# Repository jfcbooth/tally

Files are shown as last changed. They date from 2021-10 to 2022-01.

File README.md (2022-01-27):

# Tally
 
A battery-powered seven-segment display counter using a custom PCB. A counter like this can have many unique purposes and can be quickly modified to serve new purpose.
<p align="center">
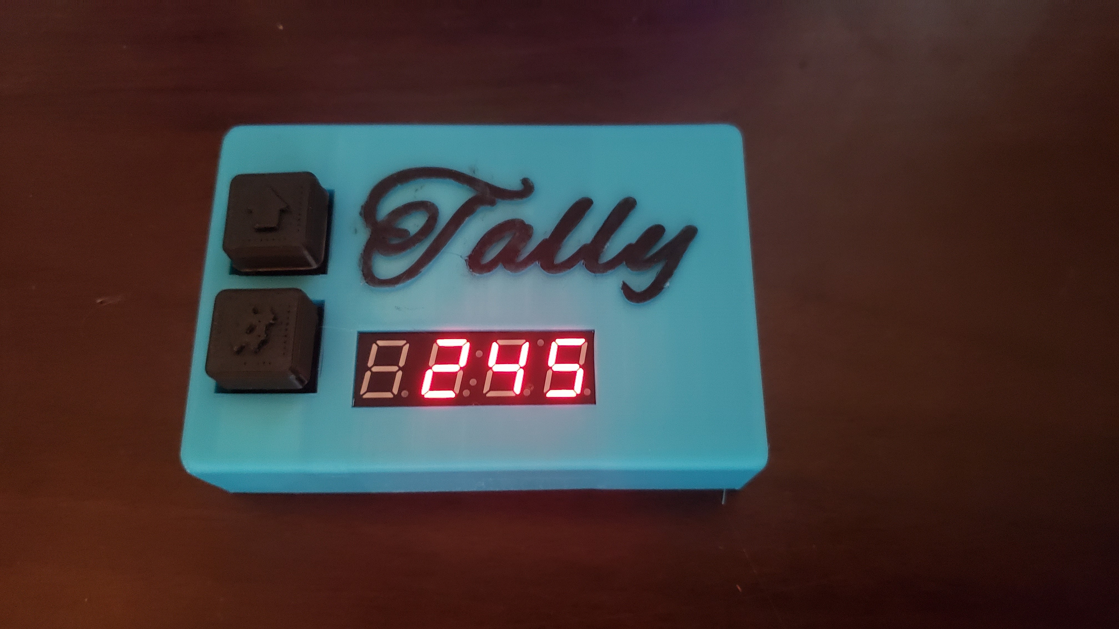
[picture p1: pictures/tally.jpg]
TT

</p>

## Resetting the tally
To reset the counter to 0, press either button to wake the device from sleep, then press the small yellow button on the back of the PCB (labelled BTN).

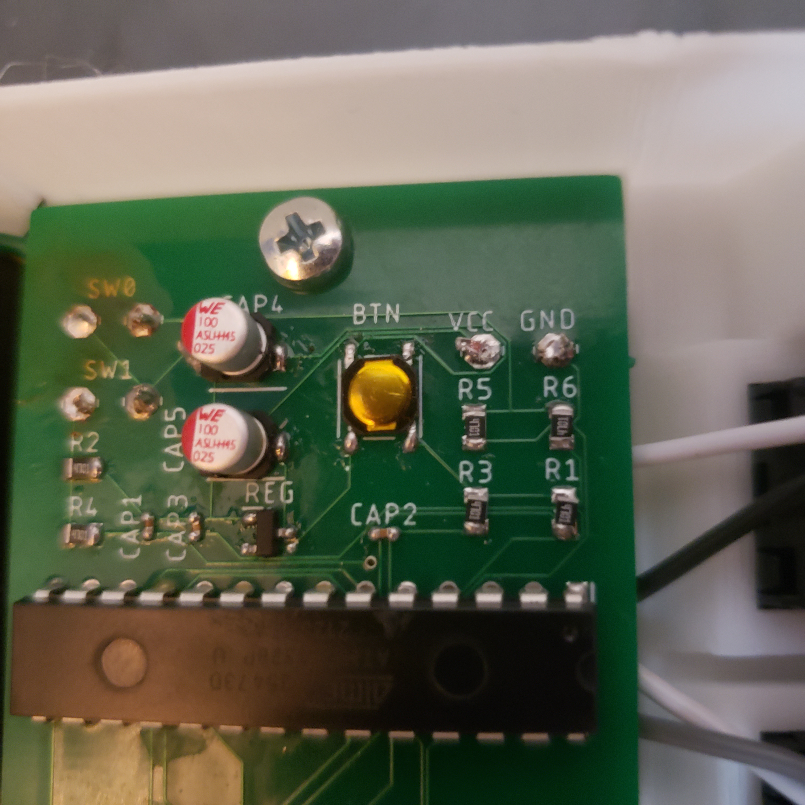
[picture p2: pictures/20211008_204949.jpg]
BTN


All files necessary to build one for yourself are included in this repository.

<!-- START doctoc generated TOC please keep comment here to allow auto update -->
<!-- DON'T EDIT THIS SECTION, INSTEAD RE-RUN doctoc TO UPDATE -->

- [ATMEGA328 Software](#atmega328-software)
- [PCB](#pcb)
- [Case](#case)

<!-- END doctoc generated TOC please keep comment here to allow auto update -->

## ATMEGA328 Software
1.) Burn Fuses
 - Open arduino software and add the MiniCore library to your board manager:  
 Preferences->Additional Board Manager URLS->paste https://mcudude.github.io/MiniCore/package_MCUdude_MiniCore_index.json  
 - Tools->Board Manager->Search "minicore"->Install  
 - Upload asrduinoISP sketch from arduino software to an arduino uno.  
 - Connect to ATMEGA as shown here:  

| Configured with internal clock | Configured with external clock |
| --- | --- |
| To flash ATMEGA | 16Mhz clock flash |

Arduino Flash Options:  
Board->Minicore->ATMEGA328P  
Clock->Internal 1Mhz  
BOD->1.8V  
EEPROM->EEPROM retained  
Compiler LTO->LTO disabled  
Variant->328P/328A  
Bootloader->No bootloader  
PORT-> select your COM port  
Programmer->Arduino as ISP  
Burn bootloader  

Trying configuring the ATMEGA328 with the internal clock first, but if the code doesn't upload, it was probably configured to use an external 16Mhz clock from the factory. You will need a 16Mhz clock which can be de-soldered from an old/dead arduino and 2 22nF capacitors. After burning the bootloader (which sets the fuses), you can remove the crystal and won't need it when uploading sketches from now on. If the code still doesn't upload, make sure all grounds are connected and the supplied voltage is >3V.

2.) Upload Sketch  
 - Open arduino sketch in src  
 - Upload as programmer  (shift click on upload button)

3.) Install ATMEGA328P into PCB  (Note the orientation)

## PCB
| Hardware | Quantity | Purchase location |
| ---  | ---  | ---  |
| ATMEGA328P-PU | 1 | [mouser](https://www.mouser.com/ProductDetail/556-ATMEGA328P-PU) |
| TDCR1050M | 1 | [mouser](https://www.mouser.com/ProductDetail/78-TDCR1050M) |
| C0402C103K5RAC7411 | 4 | [mouser](https://www.mouser.com/ProductDetail/80-C0402C103K5R7411) |
| TPS7A0520PDBZR | 1 | [mouser](https://www.mouser.com/ProductDetail/595-TPS7A0520PDBZR) |
| CRCW08054K70FKEAC | 6 | [mouser](https://www.mouser.com/ProductDetail/71-CRCW08054K70FKEAC) |
| 865080440002 | 2 | [mouser](https://www.mouser.com/ProductDetail/710-865080440002) |
| PTS526 SK08 SMTR2 LFS | 1 | [mouser](https://www.mouser.com/ProductDetail/611-PTS526SK08SMTR2L) |
| 2468 | 1 | [mouser](https://www.mouser.com/ProductDetail/534-2468) |
| Cherry MX Switch Blue | 2 | [amazon](https://www.amazon.com/Cherry-switches-MX1AG1NN-Mechanical-Keyboard/dp/B07RQTNS58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) |

I ordered my PCB's through JLCPCB.  
If ordering through them, you can just upload the tally_cam_data.zip zip file in the schematics folder to their website.  
I was supposed to be able to make this design at my university, but none of my professors know how to use the lab eqipment, so I had to order them through a 3rd party. Go Raiders!  

1.) Solder components to PCB (except cherry mx switches)  
2.) Install battery box first by sliding it into place  
3.) Screw PCB into place  
4.) Install Cherry MX switches and solder them to the board  

## Case
For the case, orient it standing tall with the cherry mx switches toward the top.  
It needs printed with a .2mm nozzle for the front lettering to print properly.  
The case is 3d printed, for the back plate, print it laying flat.

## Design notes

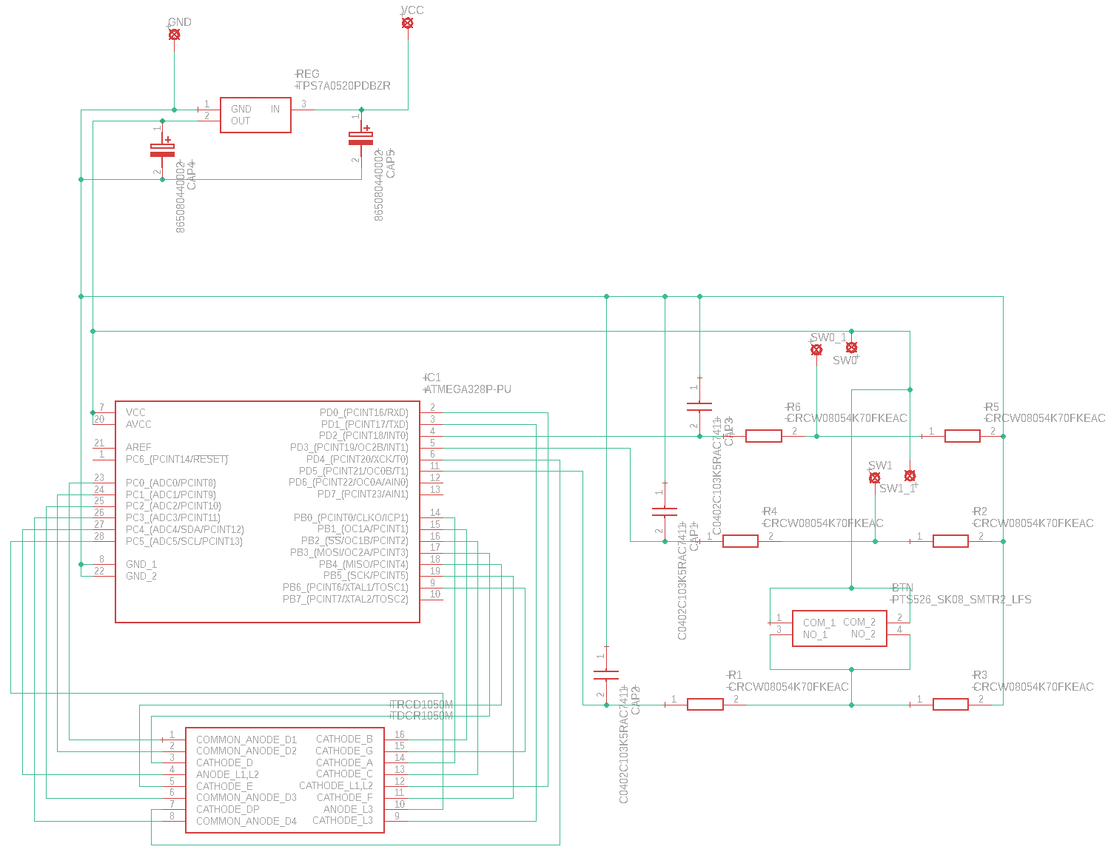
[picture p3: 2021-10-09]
pictures/tally_schematic.png

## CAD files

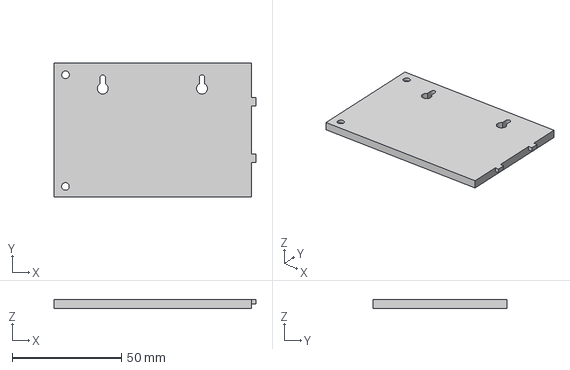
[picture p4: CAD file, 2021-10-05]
case_design/back_cover.3mf
92.6 x 61.4 x 4.00 mm

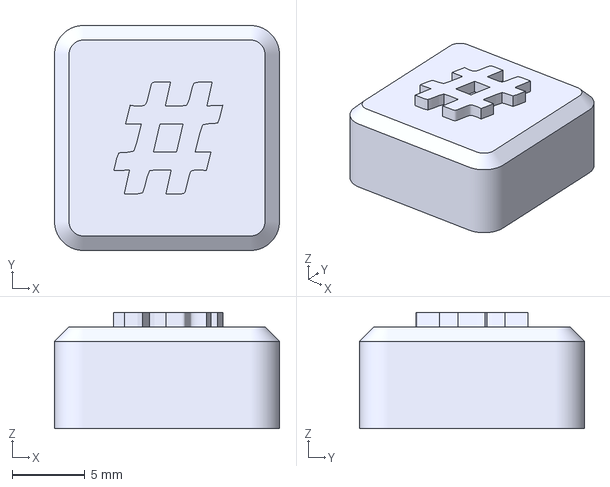
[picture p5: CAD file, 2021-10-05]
case_design/number_keycap.3mf
15.5 x 15.5 x 8.00 mm

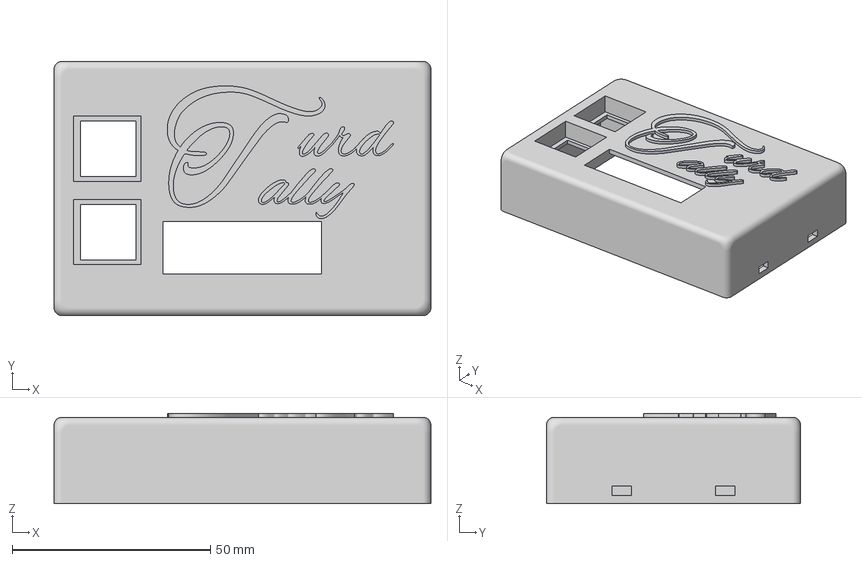
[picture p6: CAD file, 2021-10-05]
case_design/case.3mf
95.2 x 64.2 x 22.8 mm

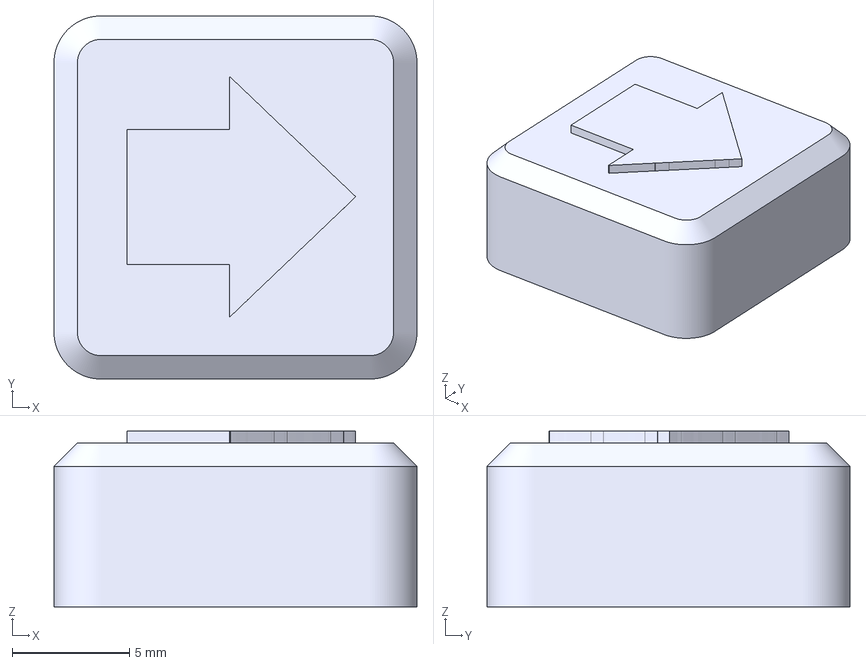
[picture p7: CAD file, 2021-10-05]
case_design/arrow_keycap.3mf
15.5 x 15.5 x 7.50 mm

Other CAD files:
case_design/up_keycap.3mf

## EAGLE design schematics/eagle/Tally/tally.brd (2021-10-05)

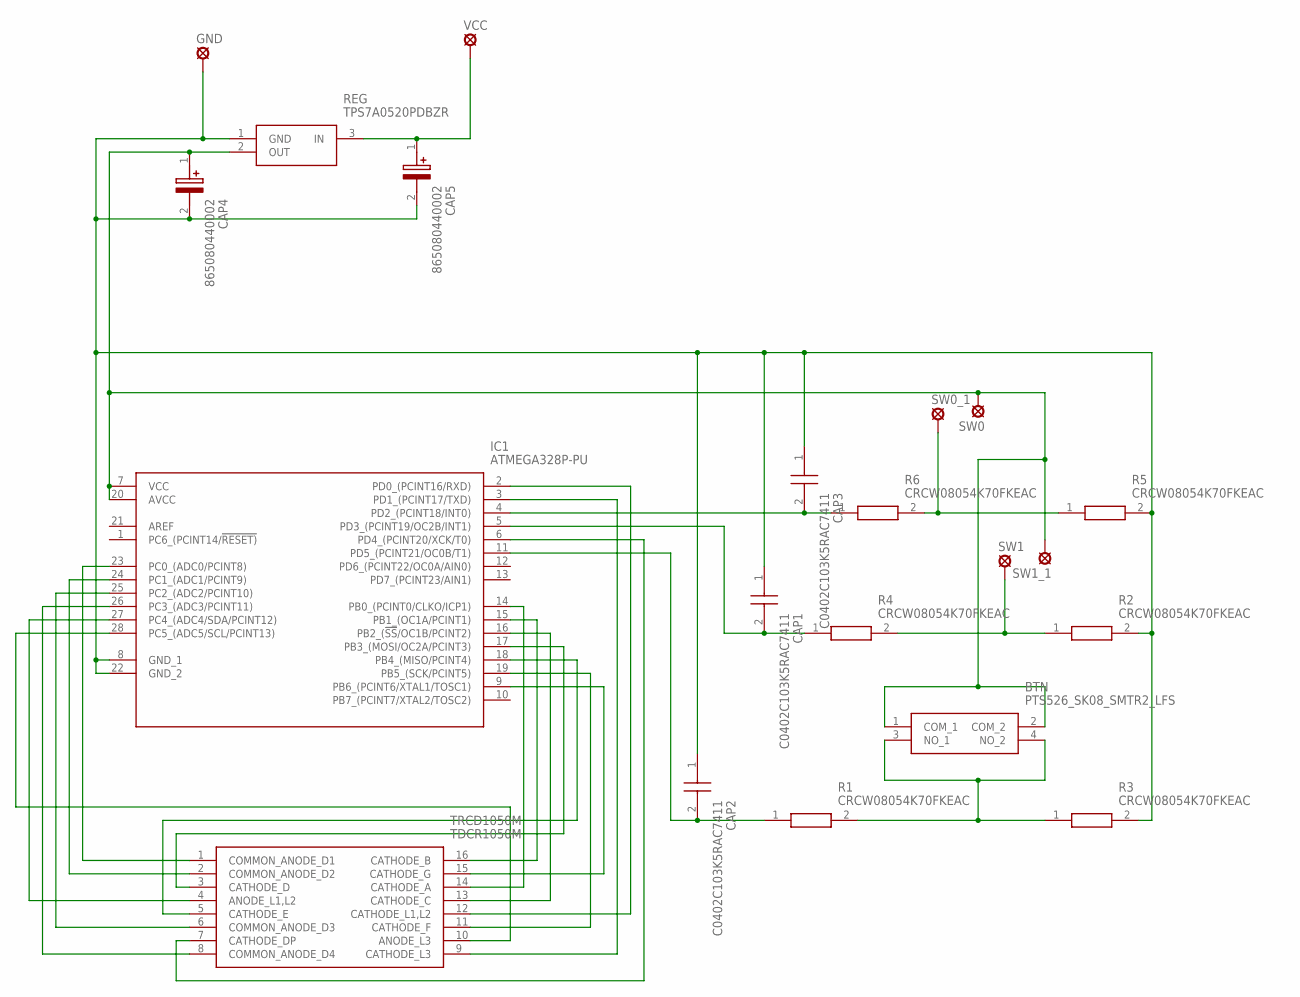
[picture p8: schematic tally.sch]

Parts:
BTN: PTS526_SK08_SMTR2_LFS; PTS526SKG15SMTR2LFS
CAP1, CAP2, CAP3: C0402C103K5RAC7411; CAPC1005X55N
CAP4, CAP5: 865080440002; CAPAE400X550N
GND: LSP11
IC1: ATMEGA328P-PU; DIP794W53P254L3467H457Q28N
R1, R2, R3, R4, R5, R6: CRCW08054K70FKEAC; RESC2012X60N
REG: TPS7A0520PDBZR; SOT95P237X112-3N
SW0, SW0_1, SW1, SW1_1: LSP11
TRCD1050M: TDCR1050M; DIPS1016W50P254L4020H725Q16N
VCC: LSP11

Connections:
unnamed: CAP1.1, CAP2.1, CAP3.1, CAP4.2 (-), CAP5.2 (-), GND.MP, IC1.8 (GND_1), IC1.22 (GND_2), R2.2, R3.2, R5.2, REG.1 (GND)
unnamed: CAP5.1 (+), REG.3 (IN), VCC.MP
unnamed: IC1.14 (PB0_(PCINT0/CLKO/ICP1)), TRCD1050M.14 (CATHODE_A)
unnamed: IC1.15 (PB1_(OC1A/PCINT1)), TRCD1050M.16 (CATHODE_B)
unnamed: IC1.16 (PB2_(!SS!/OC1B/PCINT2)), TRCD1050M.13 (CATHODE_C)
unnamed: IC1.17 (PB3_(MOSI/OC2A/PCINT3)), TRCD1050M.3 (CATHODE_D)
unnamed: IC1.18 (PB4_(MISO/PCINT4)), TRCD1050M.5 (CATHODE_E)
unnamed: IC1.19 (PB5_(SCK/PCINT5)), TRCD1050M.11 (CATHODE_F)
unnamed: IC1.9 (PB6_(PCINT6/XTAL1/TOSC1)), TRCD1050M.15 (CATHODE_G)
unnamed: IC1.23 (PC0_(ADC0/PCINT8)), TRCD1050M.1 (COMMON_ANODE_D1)
unnamed: IC1.24 (PC1_(ADC1/PCINT9)), TRCD1050M.2 (COMMON_ANODE_D2)
unnamed: IC1.25 (PC2_(ADC2/PCINT10)), TRCD1050M.6 (COMMON_ANODE_D3)
unnamed: IC1.26 (PC3_(ADC3/PCINT11)), TRCD1050M.8 (COMMON_ANODE_D4)
unnamed: IC1.27 (PC4_(ADC4/SDA/PCINT12)), TRCD1050M.4 (ANODE_L1,L2)
unnamed: IC1.28 (PC5_(ADC5/SCL/PCINT13)), TRCD1050M.10 (ANODE_L3)
unnamed: IC1.2 (PD0_(PCINT16/RXD)), TRCD1050M.12 (CATHODE_L1,L2)
unnamed: IC1.3 (PD1_(PCINT17/TXD)), TRCD1050M.9 (CATHODE_L3)
unnamed: IC1.6 (PD4_(PCINT20/XCK/T0)), TRCD1050M.7 (CATHODE_DP)
unnamed: R5.1, R6.2, SW0_1.MP
unnamed: CAP3.2, IC1.4 (PD2_(PCINT18/INT0)), R6.1
unnamed: CAP1.2, IC1.5 (PD3_(PCINT19/OC2B/INT1)), R4.1
unnamed: R2.1, R4.2, SW1.MP
unnamed: CAP2.2, IC1.11 (PD5_(PCINT21/OC0B/T1)), R1.1
unnamed: BTN.1 (COM_1), BTN.2 (COM_2), CAP4.1 (+), IC1.7 (VCC), IC1.20 (AVCC), REG.2 (OUT), SW0.MP, SW1_1.MP
unnamed: BTN.3 (NO_1), BTN.4 (NO_2), R1.2, R3.1

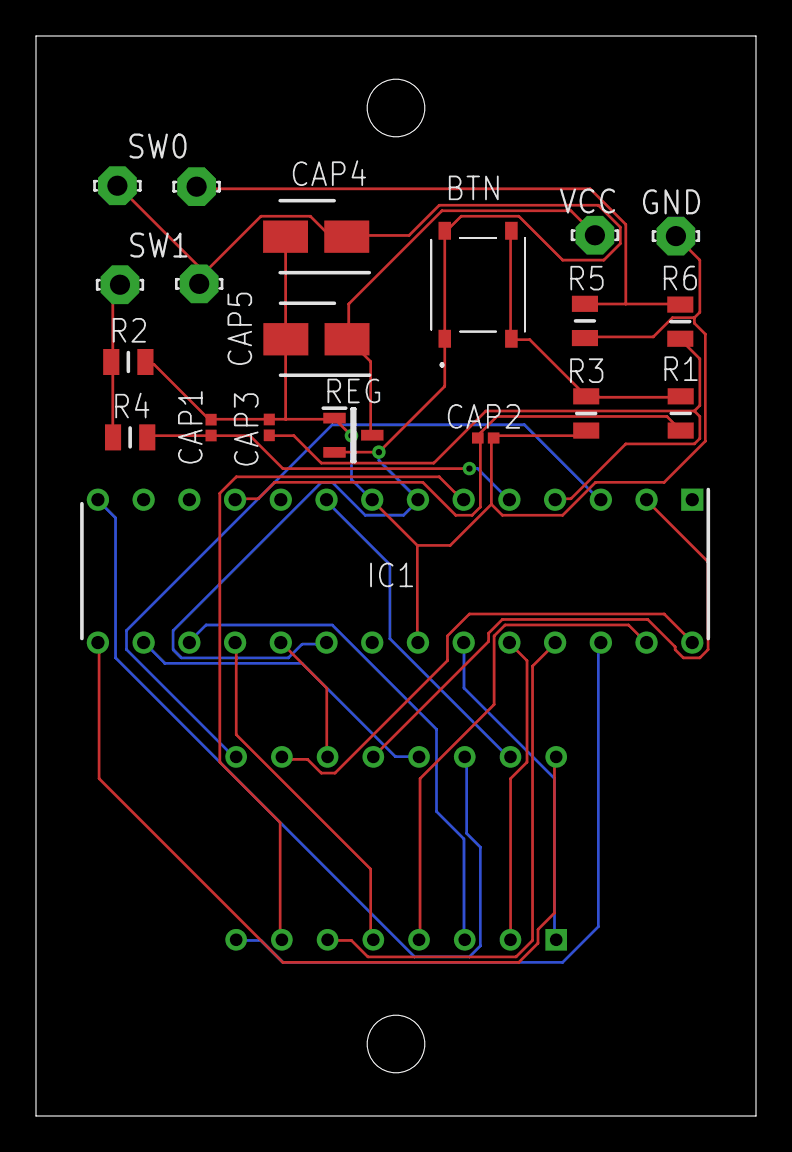
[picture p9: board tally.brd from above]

Board: 2 copper layers, 40.0 x 60.0 mm, 21 parts (1 on the bottom side), 25 nets.

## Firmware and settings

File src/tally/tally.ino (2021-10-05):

/*
 * AVR_GPIO.c
 *
 * Created: 7/27/2021 7:10:25 PM
 * Author : Josh Booth
 */ 

#undef F_CPU
#define F_CPU 1000000UL
#define DISP_ON_TIME 5
#define DIGIT_DELAY 25
#define NUM_OF_OVERFLOWS 100 // try 125 next
#define HZ_PER_1SEC 977

#include <avr/io.h>
#include <util/delay.h>
#include <EEPROM.h>
#include <avr/interrupt.h> // header to enable interrupt
#include <avr/sleep.h>

void zero(void);
void one(void);
void two(void);
void three(void);
void four(void);
void five(void);
void six(void);
void seven(void);
void eight(void);
void nine(void);
void digit_off(void);
void all_off(void);
void set_digit(int digit, int number);
void setup(void);
void display_int(int num);
void delay_1_sec(void);
void update_digits_array(int tally, int set_zero);
int read_tally(void);
void write_tally(int tally);

int turd_tally = 0; // actual tally
int disp_on_time = 0; // seconds left to keep display on for
int digits[4]; // digits to display on timer

// display current tally interrupt
ISR(INT0_vect){
  SMCR &= ~(0<<SE); // sleep_disable();
  update_digits_array(turd_tally, 0);
  disp_on_time = DISP_ON_TIME; // set number of seconds to keep display on for
  TCNT1 = 0; // reset DISP_ON_TIME timer
}

// increment interrupt
ISR(INT1_vect){
  SMCR &= ~(1<<SE); // sleep_disable();
  turd_tally = (turd_tally >= 9999) ? 1 : turd_tally+1; // make sure timer can't go above 9999
  write_tally(turd_tally); // reflect increment in EEPROM
  update_digits_array(turd_tally, 0); // change digits array so it shows on the display
  disp_on_time = DISP_ON_TIME;
  TCNT1 = 0; // reset DISP_ON_TIME timer
}

 
int main(void)
{
  setup();
  turd_tally = read_tally(); // restore value on boot
  
  all_off(); // make sure all LEDs start as off
  int digit_to_display = 0;
  int overflows = 0;
    while (true) 
    {
      
      if(TCNT1 >= HZ_PER_1SEC){ // every second decrement the number of seconds to keep the display on
        disp_on_time = (disp_on_time > 0) ? disp_on_time-1 : 0;
        TCNT1 = 0; // reset timer
      }
      // reset if reset button is pressed
      if((PIND & 0x20)){
        write_tally(0);
        turd_tally = 0;
        update_digits_array(turd_tally, 1);
      }
      // turn on display
      if(disp_on_time > 0){
        // next 2 if statments control how long each digit is displayed between the 4 digits
        if((TIFR0 & (1<<TOV1))==1){ // digit flicker timer
          overflows++;
          TCNT0 = 0; // reset timer
          TIFR0 &= 0b0;
        }
        if(overflows >= NUM_OF_OVERFLOWS){ // if enough overflows have passed, move to the next digit
          set_digit(digit_to_display+1,digits[digit_to_display]);
          digit_to_display = (digit_to_display >= 3) ? 0 : digit_to_display+1;
          overflows=0;
        }
      } else {
        PORTC = 0b00000000; // turn off the display
        SMCR |= 0b1; // enable sleep bit
        MCUCR |= (0b11<<6); // turn off brown out detection
        MCUCR |= (0b10<<6);
        asm("SLEEP"); // sleep instruction
      }
    }
                      
}

void update_digits_array(int tally, int set_zero){
  if(set_zero == 1){
    digits[3] = -1;
    digits[2] = -1;
    digits[1] = -1;
    digits[0] = 0;
    return;
  }
  static int temp_tally = -1;
  if(temp_tally != tally){ // if tally changed, recalculate digits;
    temp_tally = tally;
    for(int i = 0; i < 4; i++){
      digits[i] = (temp_tally - ((temp_tally / 10)*10));
      temp_tally /= 10;
    }
    int i = 3; // replace leading 0's with -1
    while(digits[i] == 0 && i > 0){
      digits[i] = -1;
      i--;
    }
  }  
}

// set proper bits to output
void setup(void){
    MCUCR &= (0 << PUD); // set internal pull-up resistor
    EICRA = 0b1010; // set external interrupts to occur on falling edge (button release)
    EIMSK = 0b11; // enable external interrupts 0 and 1
    sei(); // enable global interrupts
    // I/O inputs and outputs (1 == output, 0 == input)
    DDRB = 0b01111111;
    DDRC = 0b00111111;
    DDRD = 0b00010011;
    TCCR0B |= ((1 << CS12) | (1 << CS10)); // 8-bit timer, 1024 prescalar
    TCCR1B |= ((1 << CS12) | (1 << CS10)); // 16-bit timer, 1024 prescalar, 1 second passes at tick 15625
    PRR = 0b11000111;
    SMCR |= (0b010 << 1);
}

int read_tally(void){
  return ((EEPROM.read(1) << 8) |  
  
  (EEPROM.read(0) & 0b11111111));
  //return EEPROM.read(0);
}

void write_tally(int tally){
  EEPROM.write(0, (tally & 0b11111111));
  EEPROM.write(1, ((tally>>8) & 0b11111111));
}

void set_digit(int digit, int number){
  PORTC = 0b00000000; // to avoid ghosting due to the slow clock signal, turn off the digits, set the proper number bits, then turn the digit on
  switch(number){
    case 0:
      zero();
      break;
    case 1:
      one();
      break;
    case 2:
      two();
      break;
    case 3:
      three();
      break;
    case 4:
      four();
      break;
    case 5:
      five();
      break;
    case 6:
      six();
      break;
    case 7:
      seven();
      break;
    case 8:
      eight();
      break;
    case 9:
      nine();
      break;
    default:
      digit_off();
      break;
  }
  
  switch(digit){
    case 1:
      PORTC = 0b00001000;
      break;
    case 2:
      PORTC = 0b00000100;
      break;
    case 3:
      PORTC = 0b00000010;
      break;
    case 4:
      PORTC = 0b00000001;
      break;
    case 5: // colon
      PORTC = 0b00010000;
      break;
    case 6: // degree symbol
      PORTC = 0b00010000;
      break;
    default:
      PORTC = 0b00000000;
      break;
  }
}


void zero(void){
  PORTB = 0b01000000;
  PORTD |= (1<<4) | (1<<1) | (1<<2);
}

void one(void){
  PORTB = 0b01111001;
  PORTD |= (1<<4) | (1<<1) | (1<<2);

}

void two(void){
  PORTB = 0b00100100;
  PORTD |= (1<<4) | (1<<1) | (1<<2);

}


void three(void){
  PORTB = 0b00110000;
  PORTD |= (1<<4) | (1<<1) | (1<<2);

}

void four(void){
  PORTB = 0b00011001;
  PORTD |= (1<<4) | (1<<1) | (1<<2);

}

void five(void){

  PORTB = 0b00010010;
  PORTD |= (1<<4) | (1<<1) | (1<<2);

}

void six(void){
  PORTB = 0b00000010;
  PORTD |= (1<<4) | (1<<1) | (1<<2);

}

void seven(void){
  PORTB = 0b01111000;
  PORTD |= (1<<4) | (1<<1) | (1<<2);

}

void eight(void){
  PORTB = 0b00000000;
  PORTD |= (1<<4) | (1<<1) | (1<<2);

}

void nine(void){
  PORTB = 0b00010000;
  PORTD |= (1<<4) | (1<<1) | (1<<2);

}

void colon(void){
  PORTB = 0b11111111;
  PORTD = 0b00000110;
}

void degree(void){
  PORTB = 0b11111111;
  PORTD = 0b00000101;
}

void dp(void){
  PORTB = 0b11111111;
  PORTD = 0b00000011;
}

void digit_off(void){
  PORTB = 0b11111111;
}

void all_off(){
  PORTB = 0;
  PORTC = 0;
  PORTD = 0;
}

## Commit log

2021-08-18 working interrupt
2021-08-19 interrupts and sleep mode
2021-08-19 working version with push buttons
2021-08-21 fixed tally overflow and added tally reset directive
    [tally.ino]
2021-10-05 added project files
    [arrow_keycap.3mf, back_cover.3mf, case.3mf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]
